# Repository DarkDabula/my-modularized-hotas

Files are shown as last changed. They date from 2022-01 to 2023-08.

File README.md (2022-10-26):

# My Modularized HOTAS
A modularized, mostly 3D printed HOTAS with HID emulation via Arduino

## Motivation
On Christmas 2020 I stumbled over [Elite Dangerous](https://www.elitedangerous.com/) and got hooked. After a while I began to play it in VR.
At this point I realized I would need a HOTAS system. The problem was that through the pademic all systems were mostly sold out. 
I had already a joystick so I built a throttle lever made of metal parts, wood and some electronics. And it served me pretty well.

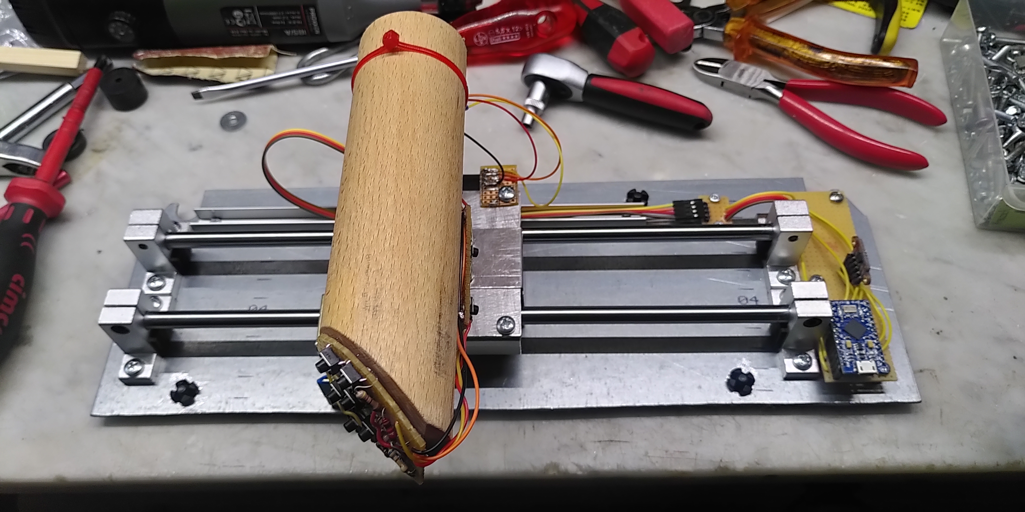
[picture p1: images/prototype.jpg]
Prototype


But after hundreds of hours I recognized that the simple push buttons got weak and that I would need more buttons for effective playing in VR.
In 2021 I bought a 3D printer and the idea was born to contruct a new and better throttle lever and maybe after this a new joystick.

## Goals
- As much 3D printed parts as possible and reasonable
- Modularized design for easy printing, assembly, customization and repair

## Current state
See [here](./status.md)

## Concepts
See [here](./concepts.md)

## External parts
For this project additional parts/components are needed besides the 3D printed ones.

| ID | Ammount | Item | Picture | Example link for buying |
|---|---|---|---|---|
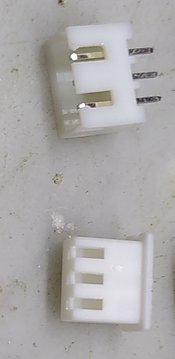
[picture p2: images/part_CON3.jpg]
Connector 3 pins
| CON3 | 3  | Connector 3 pins |  | |
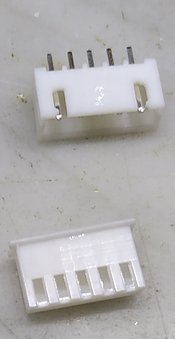
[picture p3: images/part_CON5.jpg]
Connector 5 pins
| CON5 | 1  | Connector 5 pins | | |
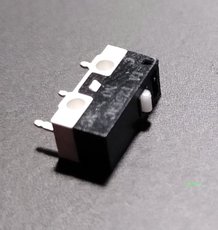
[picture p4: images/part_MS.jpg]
Micro switch
| MS | 4  | Micro swith |  | [Link](https://www.ebay.com/sch/i.html?_from=R40&_trksid=p2380057.m570.l1313&_nkw=micro+limit+switch+125V+1A&_sacat=0) | 
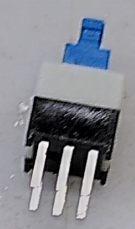
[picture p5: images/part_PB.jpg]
Push button
| PB | 10  | Push button |   | [Link](https://www.ebay.com/sch/i.html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) |
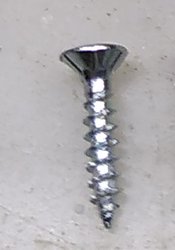
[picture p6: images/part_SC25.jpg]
Screw 2,5x13
| SC25 | 4  | Screw 2,5x13 (metric)  |  | |
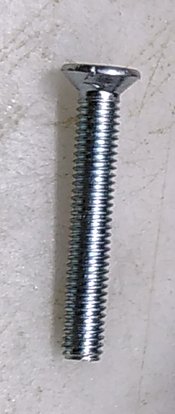
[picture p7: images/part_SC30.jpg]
Screw M3x20
| SCM3 | 1  | Screw M3x20 (metric) |  | |
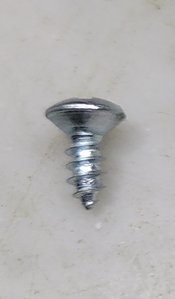
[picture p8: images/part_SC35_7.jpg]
Screw 3,5x7
| SC35_7 | 1  | Screw 3,5x7 (metric) |  | |
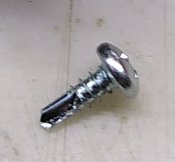
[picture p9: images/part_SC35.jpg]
Screw 3,5x9,6
| SC35_95  | 4  | Screw 3,5x9,5 (metric) |  | |
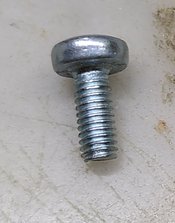
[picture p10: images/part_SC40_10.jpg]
Screw M4x10
| SCM4_10  | 8  | Screw M4x10 (metric) |  | |
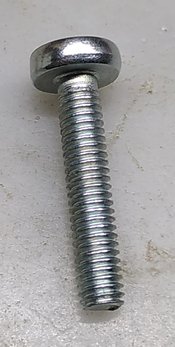
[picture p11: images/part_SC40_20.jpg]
Screw M4x20
| SCM4_20  | 2  | Screw M4x20 (metric) |  | |
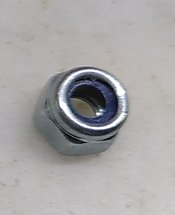
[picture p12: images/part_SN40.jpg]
Stop nut M4
| SCN4 | 2  | Stop nut M4 (metric) |  | |

## Toolchain
- [FreeCAD](https://www.freecad.org/) 0.19
- [Cura](https://ultimaker.com/software/ultimaker-cura) 4.12.1 (or above)
- [Creality Ender 6](https://www.creality.com/goods-detail/ender-6-3d-printer) (modified)
- [Arduino IDE](https://www.arduino.cc/en/software)
- [KiCad](https://www.kicad.org/)

## License
This projects is licensed under the terms of [CC BY-NC 4.0](https://creativecommons.org/licenses/by-nc/4.0/)

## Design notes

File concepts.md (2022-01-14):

# Thoughts and concepts

## HOTAS devices
### Throttle lever
The throttle lever should contain following controls
- 4 buttons and one HAT control for the thumb
- 2 buttons for the forefinger
- a rocker switch for the longfinger and fourth finger

### Joystick
- 2 buttons, one HAT control and one analogue stick
- a rocker switch for the forefinger and longfinger, the rocker switch should be able to press both buttons at the same time
- maybe more

## Modularization
To make the whole design process easier, each control(-group) will be in a separate module. The separate modules will be attached wihin the throttle lever and joystick.

### Control modules
The possible control could be put into following categories
- 2 button control
- rocker switch (two variants: one or two buttons at the same time pushable)
- HAT control
- analogue stick

### Sizes and forms
Maybe its possible to standardize the size and form of the modules so they can be exchanged. It's thinkable that the control types could be grouped in the following manner
- 2 button module, rocker switch module
- HAT module, analogue stick module

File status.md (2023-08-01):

# Status
This file will be a kind of diary for the project, to document the progress

## 1. Aug 2023
After the current lever joint got weaker and weaker I was forced to continue the project and beind able to play Elite Dangerous ^^ I printed the tow new joint parts for the new base plate. While assembling the new parts I recognized the whole cable management within the lever body is a mess. To it will be on my list when I replace the 2nd Arduino with a GPIO expander.

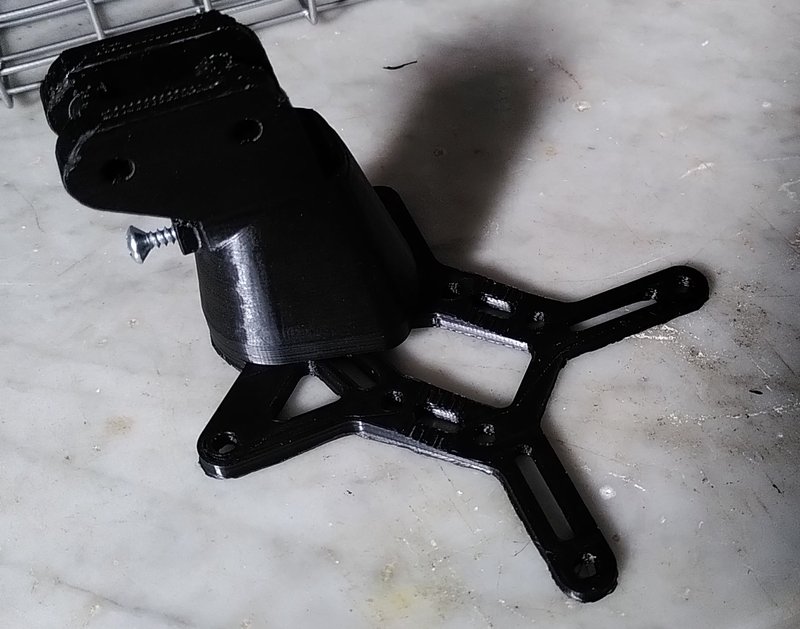
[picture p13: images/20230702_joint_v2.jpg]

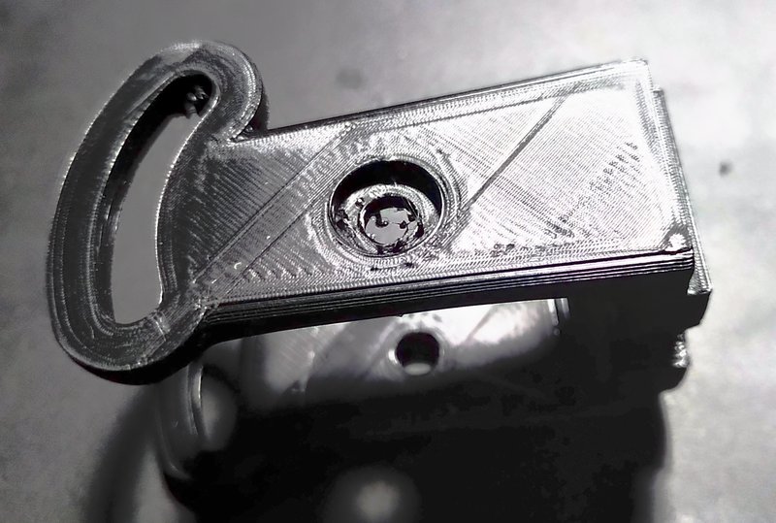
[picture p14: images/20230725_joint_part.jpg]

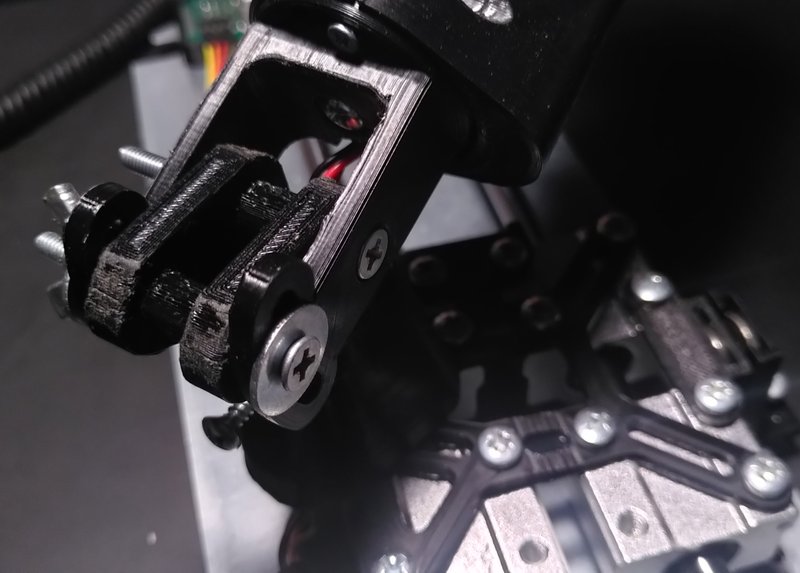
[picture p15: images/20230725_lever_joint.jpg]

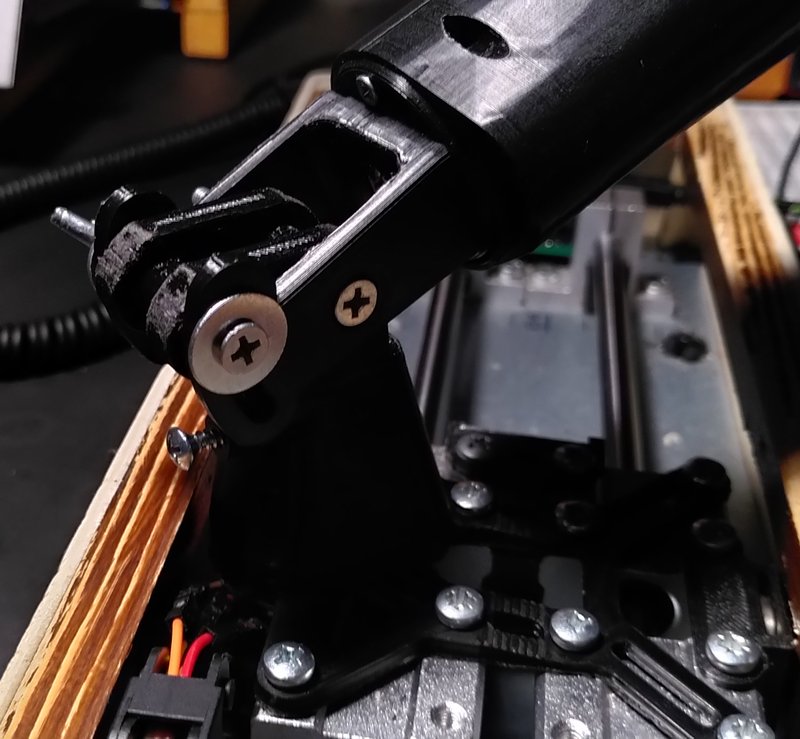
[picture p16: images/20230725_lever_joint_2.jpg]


The screws are still too long, I will replace or shorten them. The advantage is that cou can adjust the vertical angle steplessly. The joint is pretty robust so far even in stressful situations like space comat.

## 28. Jun 2023
Designed and printed a new base plate for the upcoming new lever joint.
I tried to improve stability while reducing the needed material. I also increased the size of the tunnel within the vertical joint for better cable handling.

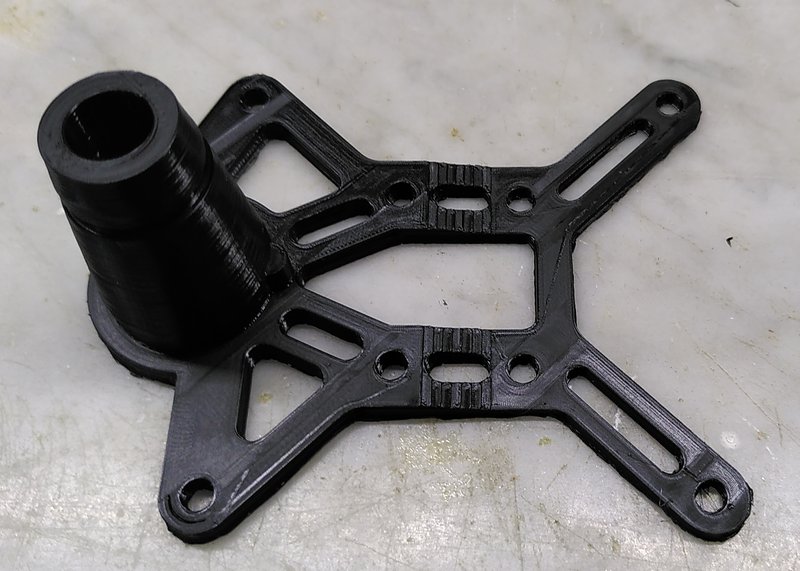
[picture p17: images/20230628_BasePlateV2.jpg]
New base plate


## 23. Apr 2023
I finished another major step, I replaced the lever head with the new version with Cherry MX switches. I am looking forward to play with them. I am not happy with the slight wiring chaos within the lever, I will try to fix it with one of the nest stages.

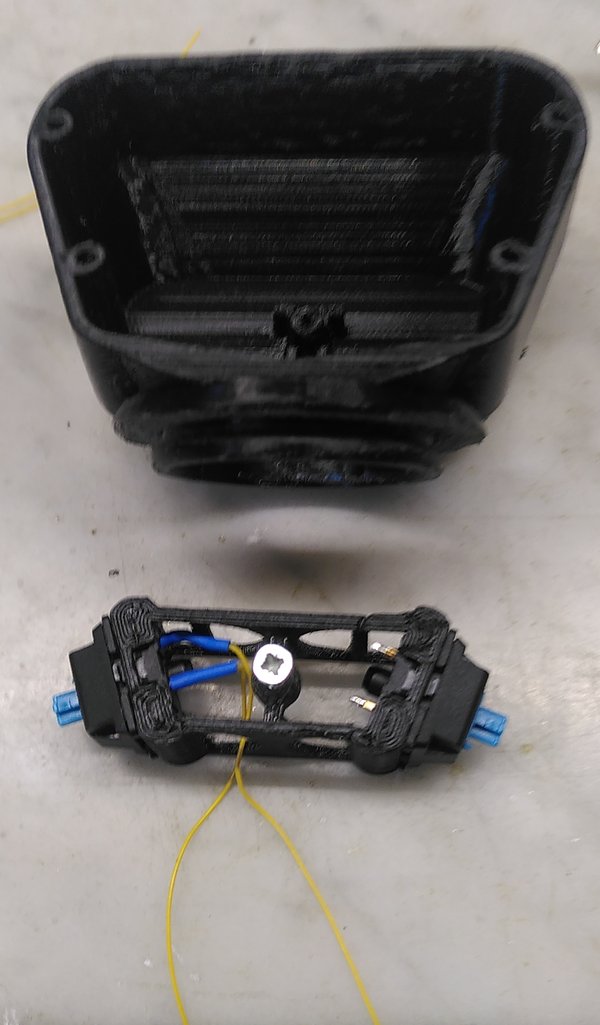
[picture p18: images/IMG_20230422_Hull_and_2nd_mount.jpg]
New hull and secondary mount

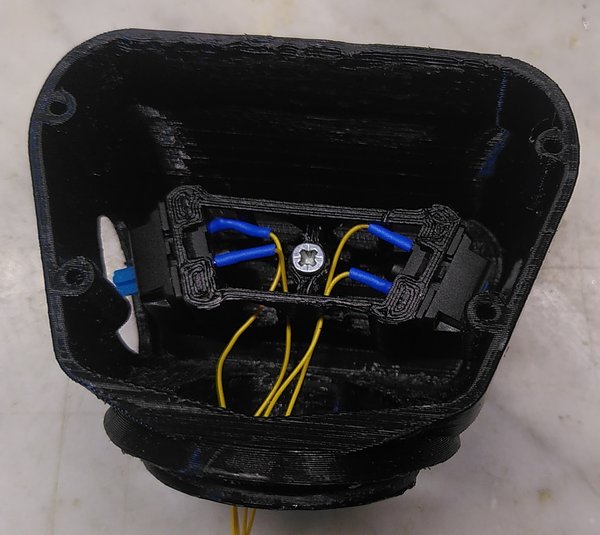
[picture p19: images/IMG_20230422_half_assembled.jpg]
Hull and secondary mount assembled

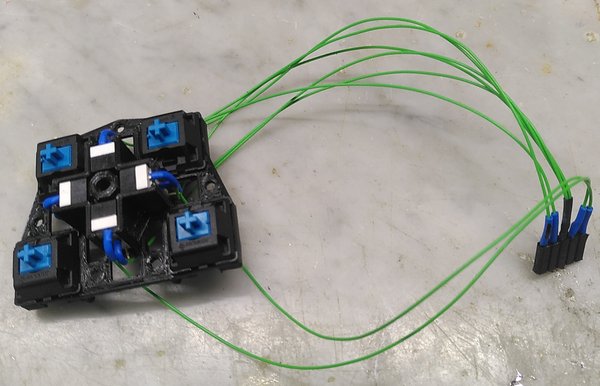
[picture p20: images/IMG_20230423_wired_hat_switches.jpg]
HAT switches wired

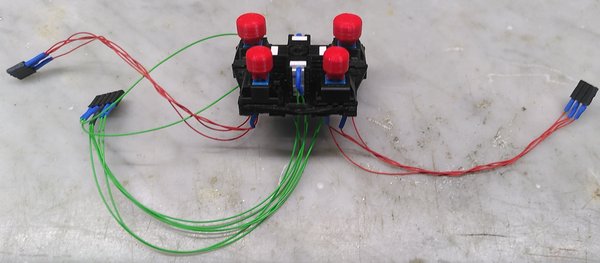
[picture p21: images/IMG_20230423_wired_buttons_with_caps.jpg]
Wired switches and attached caps

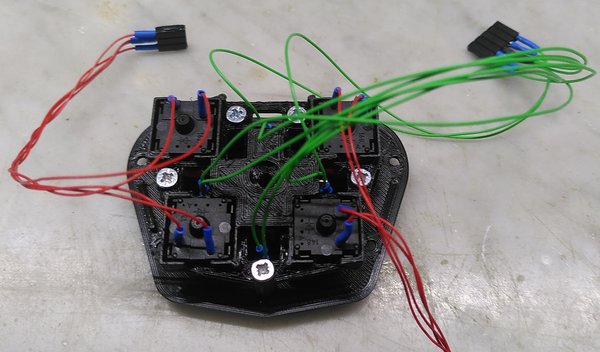
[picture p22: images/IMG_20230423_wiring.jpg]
Wiring from below

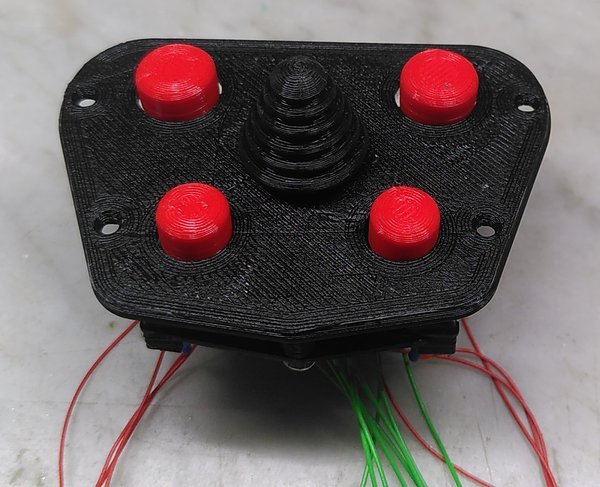
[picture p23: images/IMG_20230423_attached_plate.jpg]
Attached cover plate

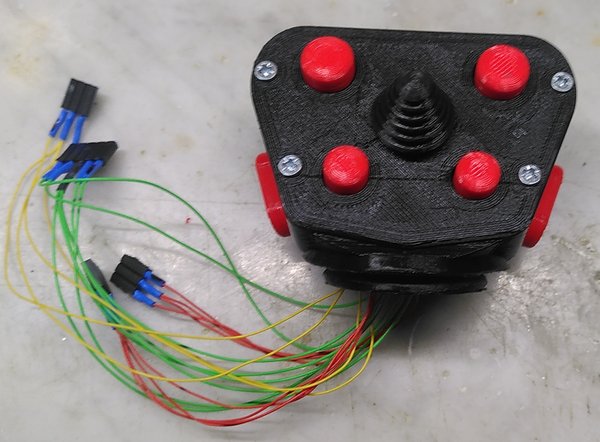
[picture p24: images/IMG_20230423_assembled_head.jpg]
Fully assembled lever head

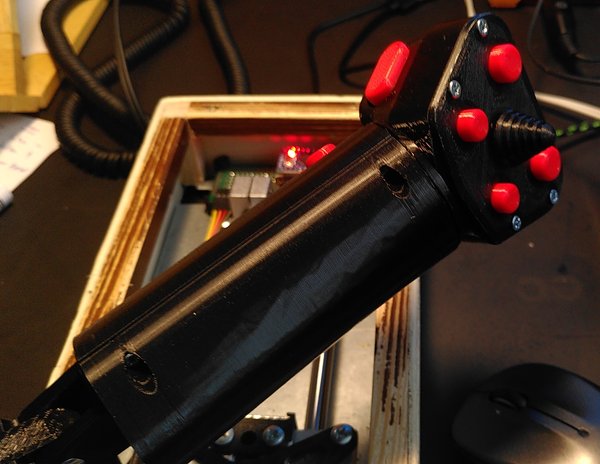
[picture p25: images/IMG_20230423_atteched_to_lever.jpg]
New head attached to lever


The next steps will be
* Replacing the weak mount to the base
* Replacing the inner Arduino and complex resistor board board by an I2C GPIO expander
* Improving wire management

## 06. Mar 2023
Yesterday I completed and assembled the new redesigned lever body. Now there will be Cherry switches for the rocker and the two main buttons. The new body is mostly compatible with the other legacy parts.

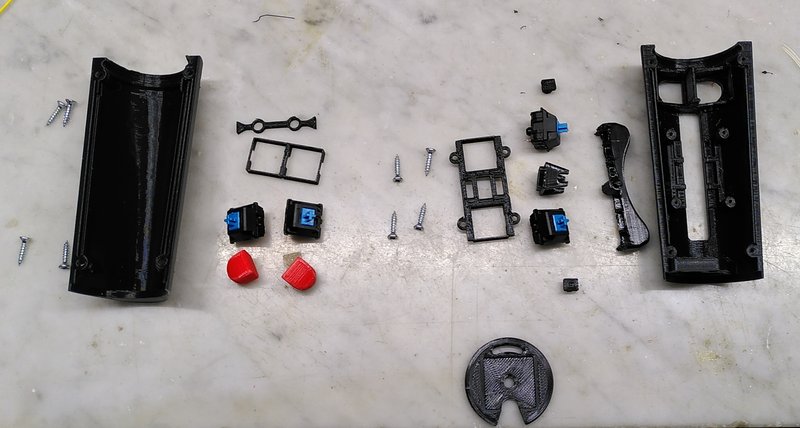
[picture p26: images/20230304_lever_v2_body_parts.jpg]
Parts for lever body V2

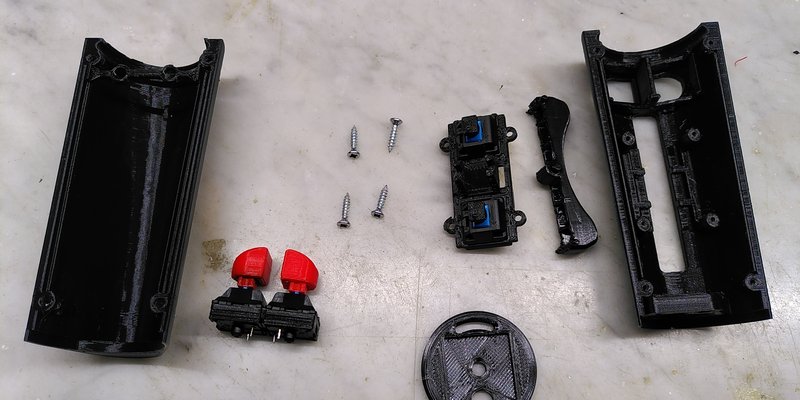
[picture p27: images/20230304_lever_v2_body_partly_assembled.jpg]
Parts for lever body V2 assembled

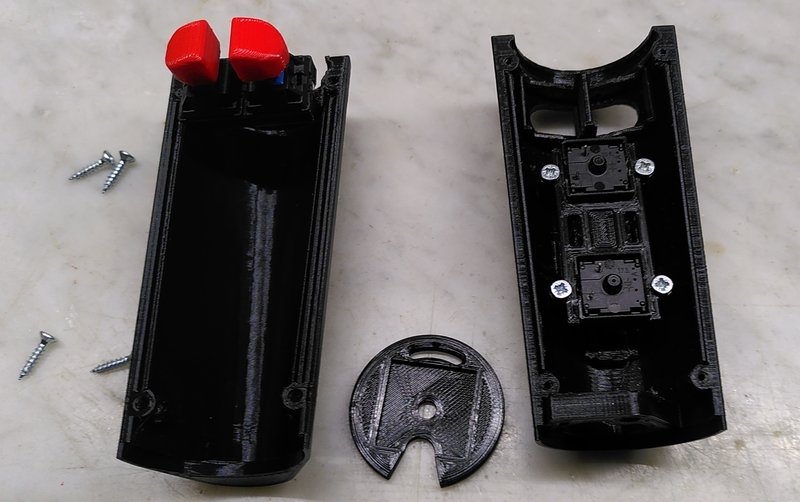
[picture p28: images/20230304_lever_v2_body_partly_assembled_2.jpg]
Parts for lever body V2 assembled

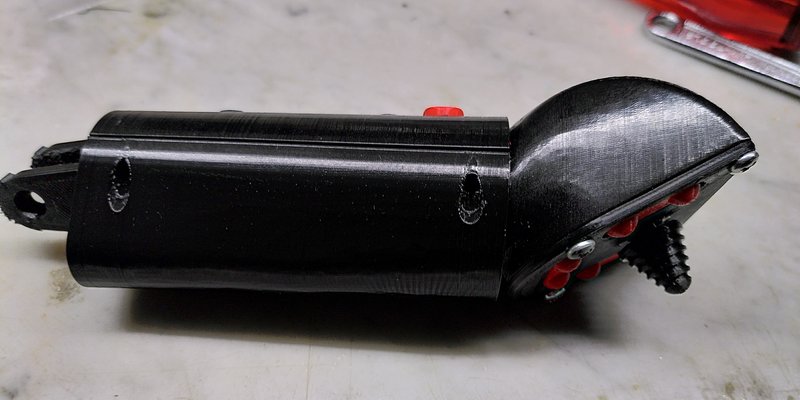
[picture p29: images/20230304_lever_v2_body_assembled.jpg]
Lever body V2 assembled


To connect the cherry keys I use thinner wires and female sockets as connector which fits into the original board connectors.

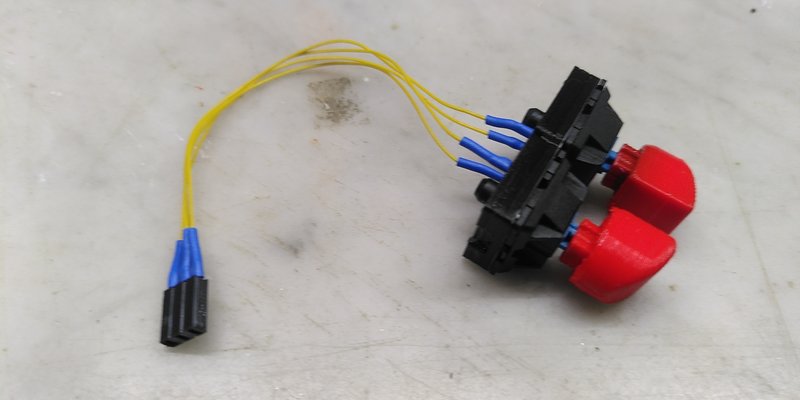
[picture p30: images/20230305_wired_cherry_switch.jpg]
Wired Cherry switches

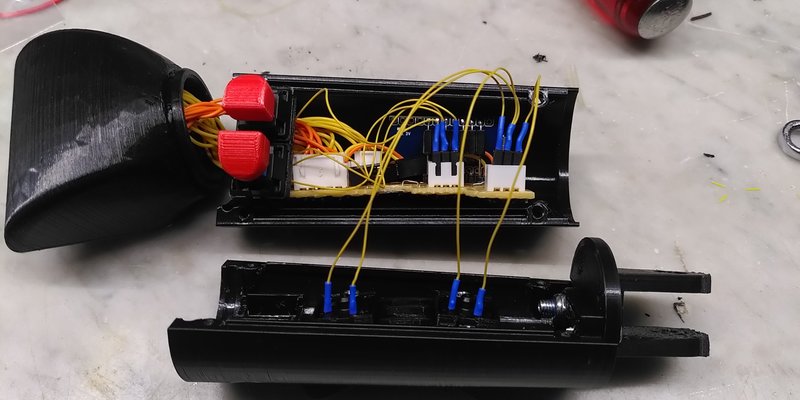
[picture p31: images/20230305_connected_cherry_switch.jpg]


The next steps will be (maybe not in this order):

- Redesign of the lever joint
- Redesign of the HAT-button-panel
- Replacing the inner Arduino and connector board by an I2C GPIO expander

I played already several hours with the new lever and so far all in fine. The Cherry switches are softer and need less pressure. Hopefully the (used) Cherry switches will be more durable.

## 05. Feb 2023
Still playing a lot Elite Dangerous with the current HOTAS design and yes, the blue push buttons are crap. The most stressed button have to be replaced regularly and I am going to run low on replacements.

So I ordered an used Cherry keyboard and desolded the switches. The I designed an printed some prototypes as mount and key cap.

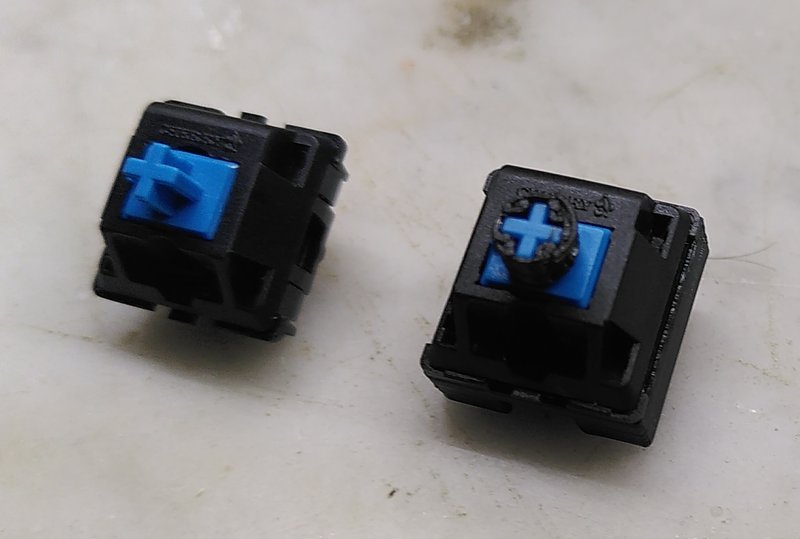
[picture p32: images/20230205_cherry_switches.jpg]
Cherry MX switches with mount prototypes


The next steps will be to redesign the lever and some other parts around the new switches.

## 23. Dec 2022
I printed a cable mount so there will be no mechanical force on the Arduino board anymore.

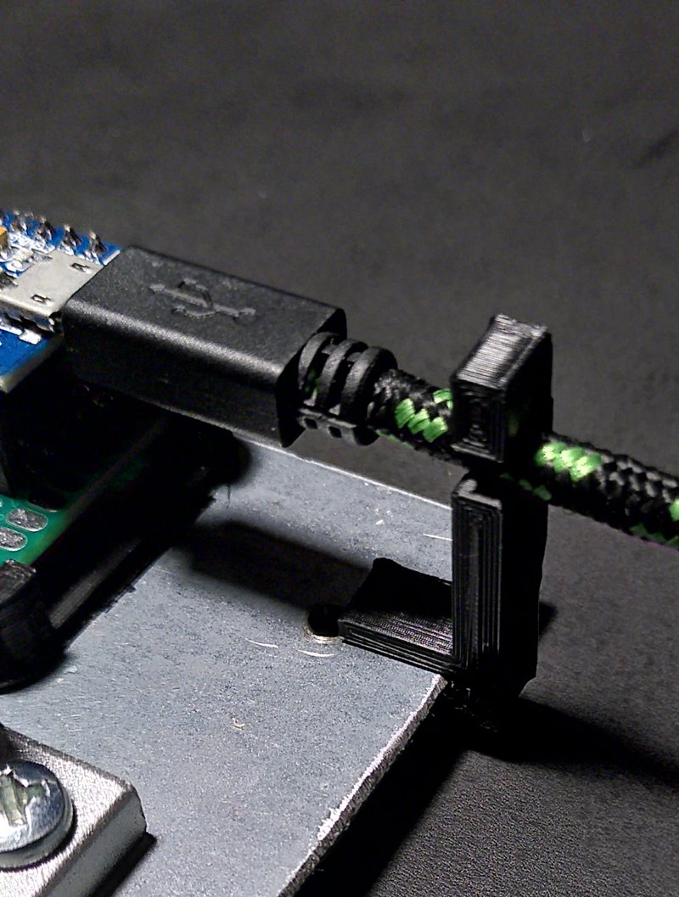
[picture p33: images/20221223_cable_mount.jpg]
Cable mount


I also located some weak points of the construction after several hours playing Elite Dangerous:

- The lever joint seems not strong enough to hold the lever in the adjusted position when pushed to hard
- Some of the push button are getting unreliable. Maybe they don't have the quality I thought. Maybe ne next time I will use real Cherry buttons when possible.
- The circuit with the resistant maybe isn't the best option with the tolerance of the buttons, maybe the next stage will be using a I2C GPIO expander to get an input for every button. 

## 20. Nov 2022
I optimized the code of the master Arduino to improve the throttle control, now it works fine.

I also redesigned the magnet mount for the metal base plate. Unluckily I broke some uncritical parts of it while inserting the magnet.
The new mount have a better adhesion to the plate.

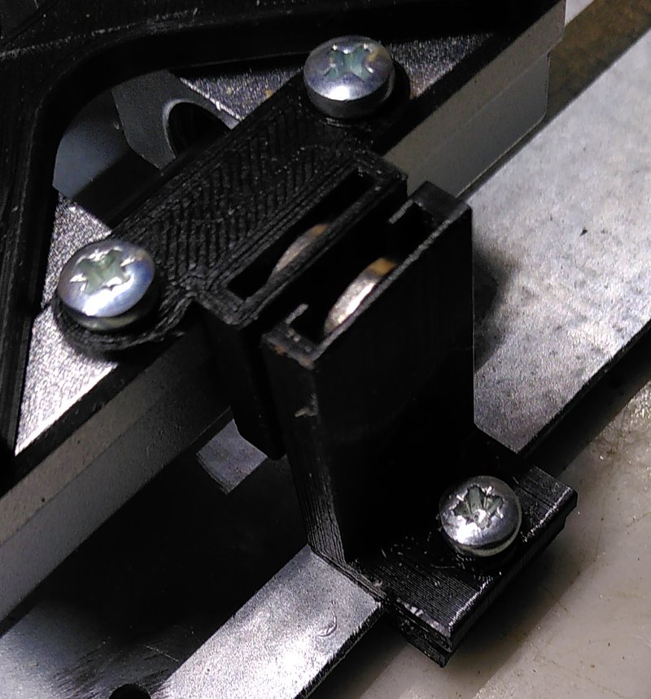
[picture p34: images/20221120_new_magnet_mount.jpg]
New magnet plate mount


I printed a mount for the front board and attached it to the metal base plate.

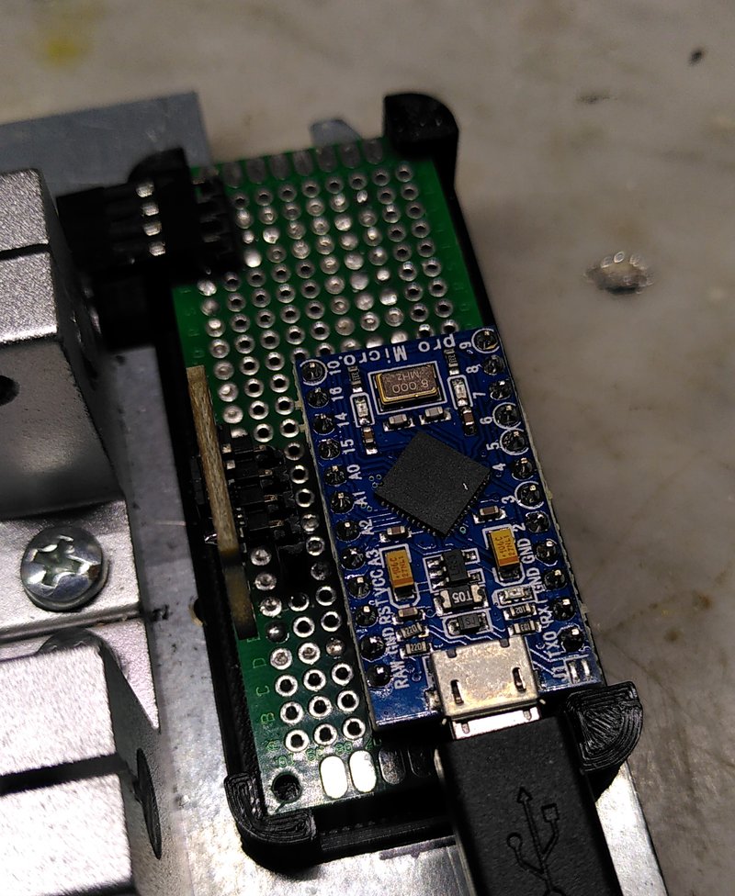
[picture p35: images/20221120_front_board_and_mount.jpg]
Front board and mount


Next step will be to create a case for the whole thing and finalize the cable management.

## 17. Nov 2022
I fixed some issues which occurs while playing.

1. Broken cable at one of the rocker switches
2. Replaced one rocker switch which had more than 30 Ohm while pressed
3. Fixed software bug in slave program which reports invalid values to master via I2C

I also finished the front board with the connectors for cable, time-of-flight sensor and master Arduino

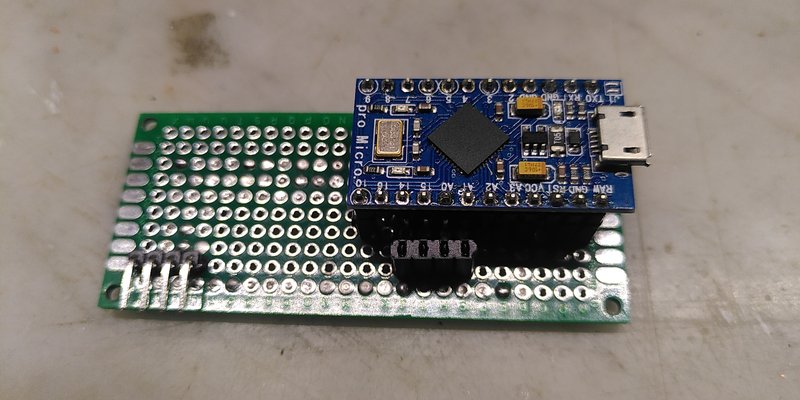
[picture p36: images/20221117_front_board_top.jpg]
Front board top

Front board bottom

Next step is to print a mount for the front board.

## 14. Nov 2022
I wired and assembled the lever

Lever interior
Lever assemlbed

I also printed the last parts for the magnets which "mark" the zero position

Lever interior

and the reflector for the time-of-flight sensor using a small piece of aluminum

Lever interior

I finished the programming of the Arduinos. A strange thing is that sometimes the master gets values over I2C which the slave don't send. 
But luckily I was able to compensate it via programming.

Finally I finished my first session Elite Dangerous with the new lever and configured the key bindings.

## 11. Nov 2022
I finished the connector board

Connector board front
Connector board back

But despite all digital planning I had to modify some parts because the Arduino collided with the 4-pin connector on the side

Connector board modified

1. Removed the plastic spacer to lower the height
2. Cable connection instead pins
3. Increased angle of connector

With that all fits together well

Connector board assembled

I also tested the whole setup with both Arduino boards.

Two Arduinos connected

Next steps will be:

* Finish programming
* Assemble thrust lever
* Create electric connections

## 04. Nov 2022
I designed a placeholder for the boards within the lever to get a feeling for the available space.

Board placeholder

Then I imported the shape into KiCad and puzzled to get all parts arranged within it.

Connector board front
Connector board back

Now I wait for some parts that I ordered to assemble the connector board.
I also continued developing the Arduino sketch for the slave controller.

## 26. Oct 2002
I designed the connector boards with KiCad. These boards will be connected to the buttons and will translate them into analogue signals for the slave Arduino. Maybe this will not be the final design.

Connector boards front
Connector boards back

I also created a physical version, but its not perfect. So I consider to call it prototype.

Connector one board front
Connector one back front

Besides that I began to program the slave Arduino. Results are promising so far.

## 19. Oct 2022
I reached a major milestone within this project. All basic parts of the lever are designed and printed. 

Lever front
Lever back
Lever opened

Not all is perfect but I think it will go through some iterations while using it, but for now I am happy wight the result.

The next phase will be wiring all the buttons, create connector boards and programming the controller. Challenging will be the limited space within the lever.

## 18. Oct 2022
I finally printed the two parts of the lever hull. I printed them separately in two runs. At the first part I struggled to strip the support structure away. So at the second
part I used tree support.

Lever hull parts

There a still some little tasks ahead: 
- reprint of the lever angle stopper -> seems to be too small
- print the final version of the rocker
- print the final version of the rocker module
- designing and printing the front buttons of the lever

## 08. Oct 2022
I redesigned the rocker module to use the new push buttons and omitting the springs.

New rocker module in parts
New rocker module assembled

## 03. Oct 2022
The right panel is now fully assembled and wired. One major step is done.

Right panel assembled

Next phase is the final design for the lever corpus.

## 28. Sep 2022
It took four attempts to print a perfect fitting HAT. I am pretty happy how it worked out finally. The next step will be to create an assembly description with the needed screws and other parts.

Right panel with HAT

## 27. Sep 2022
The right panel makes progress. I printed the cover plate an the double button caps. The next step will be printing the HAT and add the missing wires.

Right panel and button caps

## 26. Sep 2022
At the moment I am eager to play Elite Dangerous again, so I am pretty motivated to push this project forward ;)
Today I printed the (maybe final) panel for the buttons and the HAT module. I also printed a button cap prototype.
A small problem will be wiring the HAT module because there isn't much space.

Right panel and button cap prototype 

## 25. Sep 2022
I am designing the right main button panel of the thrust lever at the moment. I plan to put there 6 buttons and a HAT.
The HAT module gave me a pretty hard time. First I wanted to use the new blue button but I didn't get the mechanics to work.
So I went back to the first micro switches and with that I got a promising prototype.

Right panel parts prototypes

The next step will be to integrate the HAT module into the panel construction.

## 20. Aug 2022
I designed the right part of the lever where many of the buttons and the HAT will be located. The print went pretty well.

Left part of the lever

I am also struggling designing the button modules. The problem is that the switches I wanted to use aren't pretty compact. So I ordered some others at EBAY hoping that they are as reliable as the old ones.

Switches

## 11. Aug 2022
I designed and printed additional parts for test reasons.

New parts

The consists of:
- Two stoppers to set horizontal angle
- Connector and connection plate to connect the lever with the joint with possible rotation around a additional axis
- Partial printed lever hull, which consists of two parts but I put them too close while printing this time
- Stopper to adjust rotation angle of the lever around its inner axis, not completely assembled

The result is promising but I also identified some weak points.

New parts assembled

There is also room for some optimizations like the amount of needed material.

## 07. Aug 2022
I did a second prototype for a part of the joint that will connect lever and base plate. With the screw the joint can be fixed in its position. The print wasn't 100% accurate but luckily it was at a non-critical point.

2nd prototype base joint
2nd prototype base joint on baseplate

## 06. Jun 2022
I redesigned the base plate to reduce need of filament. Additionally I replaced the original lock-in position by a kind of gear to allow finer angles of adjustment around the vertical axis.
I also do a test print ob the counterpart for it.

2nd prototype of base plate  

## 07. Feb 2022
Printed the first version of the base plate with joint. We will see if the joint is strong and stiff enough.

Base plate

## 06. Feb 2022
Replaced the original metal base plate by a thin printed prototype to check if the holes where at the right position. On the base plate there will a joint to connect it with the lever.

Base plate prototype

## 31. Jan 2022
I created the first test pieces for the adjustable joint. With that it should possible to adjust the angle of the lever in relation to the horizontal line. This was my third try after evaluating other designs.

Joint prototype

## 20. Jan 2022
I did a small revision of the rocker switch module. Its slightly smaller and have holes to reduce material. The rocker itself is black because I was too lazy to change the filament for the test print. ^^

Rocker switch revision 1

## 14. Jan 2022
Today I printed the early version of parts for the rocker switch and assembled them with the switches and springs.

First rocker switch

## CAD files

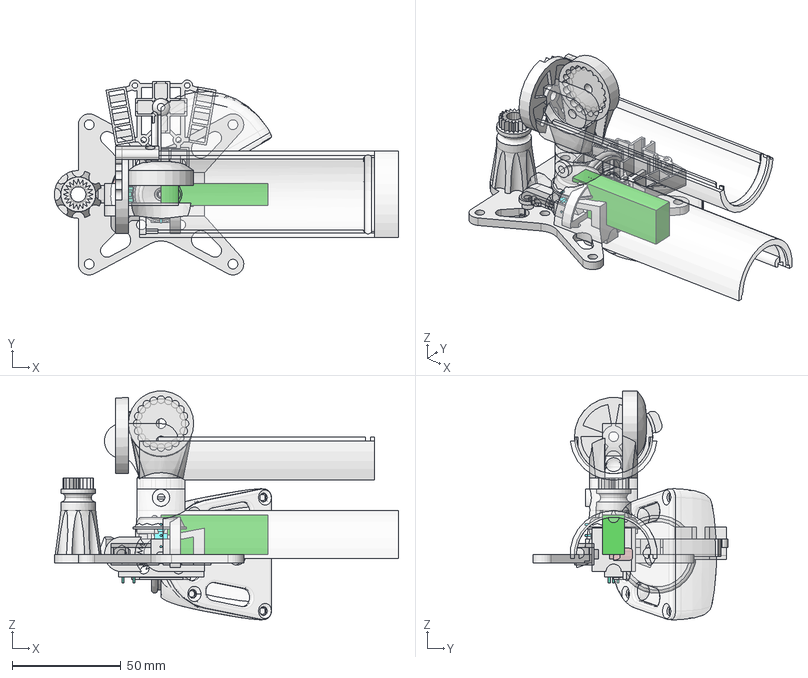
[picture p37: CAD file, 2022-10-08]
freecad/MMHOTAS Throttle Lever.FCStd
157.9 x 89.5 x 105.0 mm
rocker
Micro Switch
Spring
rocker plate bottom
rocker plate top
ProMicro
Plate
Platejoint-Base
Foundation
Vertical adjustable Joint
Vertical joint cap
Joint Connector front
Joint Connector back
Platejoint-Head
Platejoint-Gear
Teeth ring
Adj vertical joint
lc base
Lever front stopper teeth
Lever front stopper base
Lever back stopper teeth
Lever back stopper base
Lever Connector Plate
lc teeth back
lht left end
lht side profile
lhd side profile
Lever Stopper Top
lbpc tube
lbcp ring
lbp plate
tbm switch 2
bc body
bc button north
bc button east
bc button south
bc button west
HAT cap A
HAT cap B
lbpm front buttons
lbpm top buttons
lbpm bottom buttons
HAT cap C
HAT Axe Ring
HAT Switch West
lbpm hat
lbpm front support
lbpm back top support
lbpm back bottom suport
Double Button Cap
HAT Axe Ring 2
rocker body
rm button left
rm button mount
rm rocker mount 2

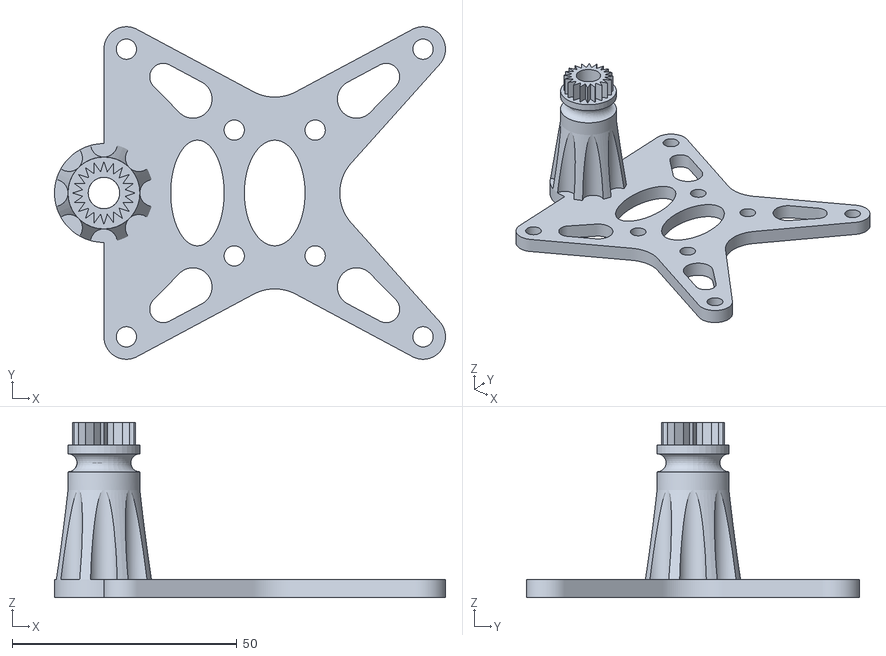
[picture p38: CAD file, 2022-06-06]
stl/MMHOTAS Throttle Lever-Baseplate.stl
87.0 x 74.0 x 39.0

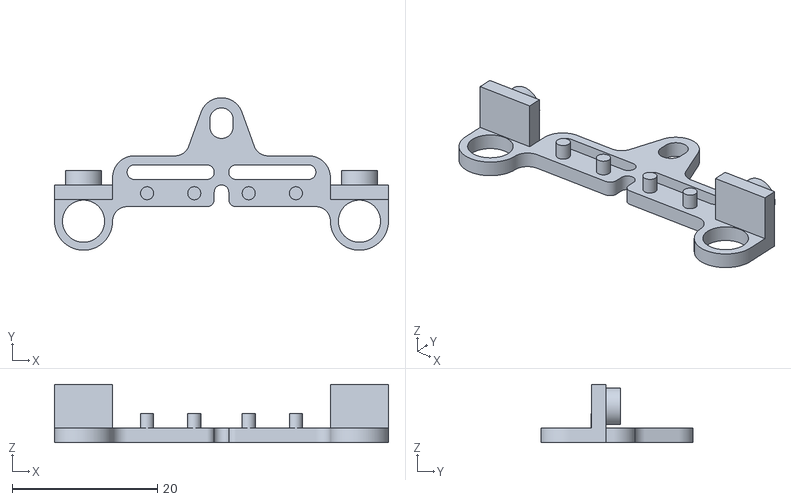
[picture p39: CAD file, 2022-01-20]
stl/MMHOTAS Throttle Lever-rocker module-rocker plate bottom.stl
46.0 x 21.0 x 8.00

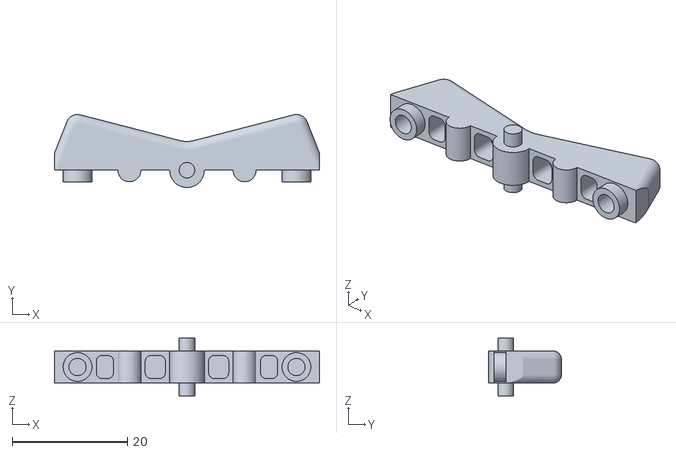
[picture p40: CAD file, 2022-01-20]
stl/MMHOTAS Throttle Lever-rocker module-rocker.stl
46.0 x 12.7 x 10.0

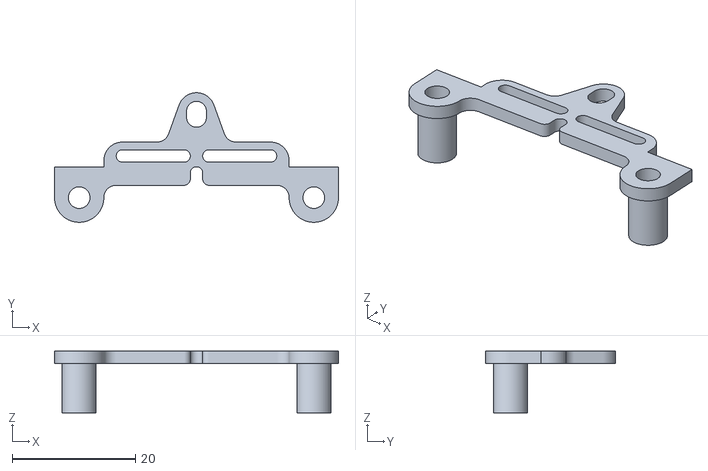
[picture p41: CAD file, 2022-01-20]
stl/MMHOTAS Throttle Lever-rocker module-rocker plate top.stl
46.0 x 21.0 x 10.0

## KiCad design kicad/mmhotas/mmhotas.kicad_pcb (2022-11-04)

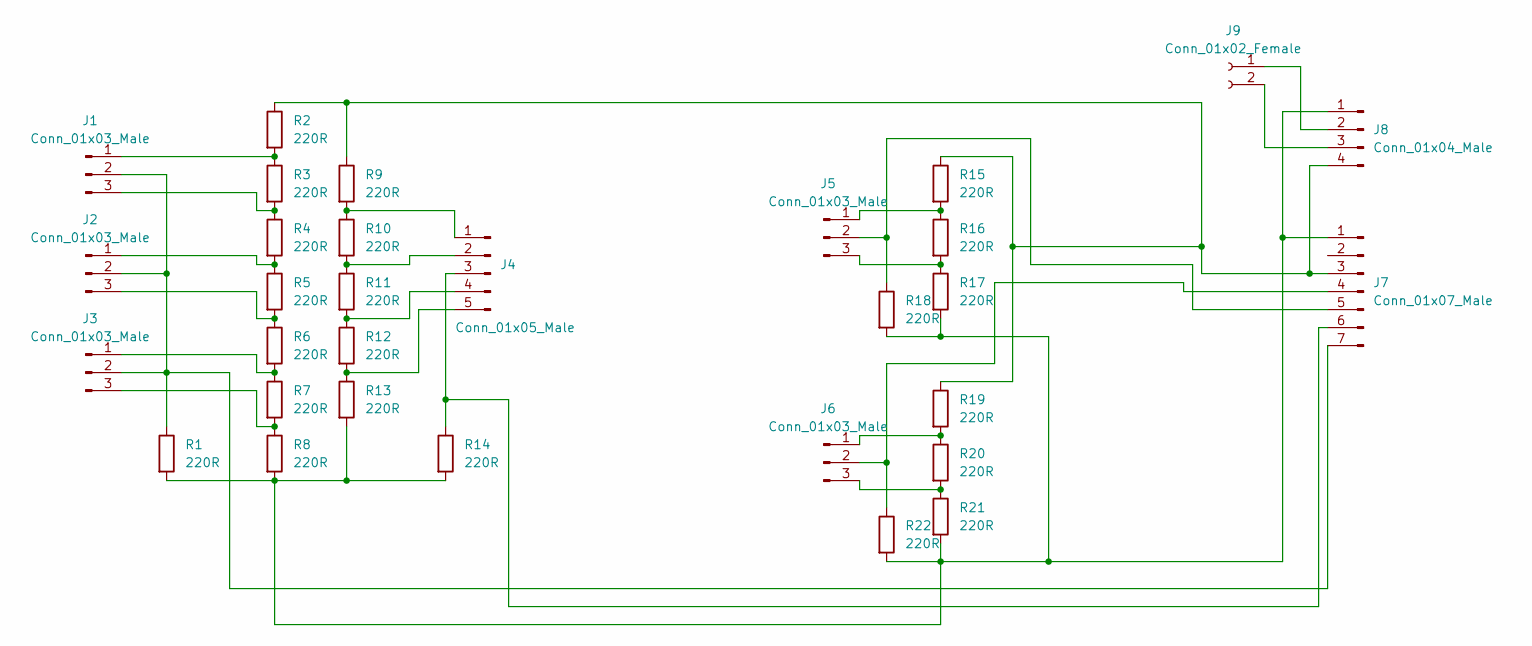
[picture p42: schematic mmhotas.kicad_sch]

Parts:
J1, J2, J3, J5, J6: Conn_01x03_Male; JST_XH_B3B-XH-A_1x03_P2.50mm_Vertical
J4: Conn_01x05_Male; JST_XH_B5B-XH-A_1x05_P2.50mm_Vertical
J7: Conn_01x07_Male; PinHeader_1x07_P2.54mm_Vertical
J8: Conn_01x04_Male; PinHeader_1x04_P2.54mm_Horizontal
J9: Conn_01x02_Female; PinSocket_1x02_P2.54mm_Vertical
R1, R2, R3, R4, R5, R6, R7, R8, R9, R10, R11, R12, R13, R14, R15, R16, R17, R18, R19, R20, R21, R22: 220R; R_1206_3216Metric

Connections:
unnamed: J1.1, R2.2, R3.1
unnamed: J1.2, J2.2, J3.2, J7.7, R1.1
unnamed: J1.3, R3.2, R4.1
unnamed: J2.1, R4.2, R5.1
unnamed: J2.3, R5.2, R6.1
unnamed: J3.1, R6.2, R7.1
unnamed: J3.3, R7.2, R8.1
unnamed: J4.1, R9.2, R10.1
unnamed: J4.2, R10.2, R11.1
unnamed: J4.3, J7.6, R14.1
unnamed: J4.4, R11.2, R12.1
unnamed: J4.5, R12.2, R13.1
unnamed: J5.1, R15.2, R16.1
unnamed: J5.2, J7.5, R18.1
unnamed: J5.3, R16.2, R17.1
unnamed: J6.1, R19.2, R20.1
unnamed: J6.2, J7.4, R22.1
unnamed: J6.3, R20.2, R21.1
unnamed: J7.1, J8.1, R1.2, R8.2, R13.2, R14.2, R17.2, R18.2, R21.2, R22.2
unnamed: J7.3, J8.4, R2.1, R9.1, R15.1, R19.1
unnamed: J8.2, J9.1
unnamed: J8.3, J9.2

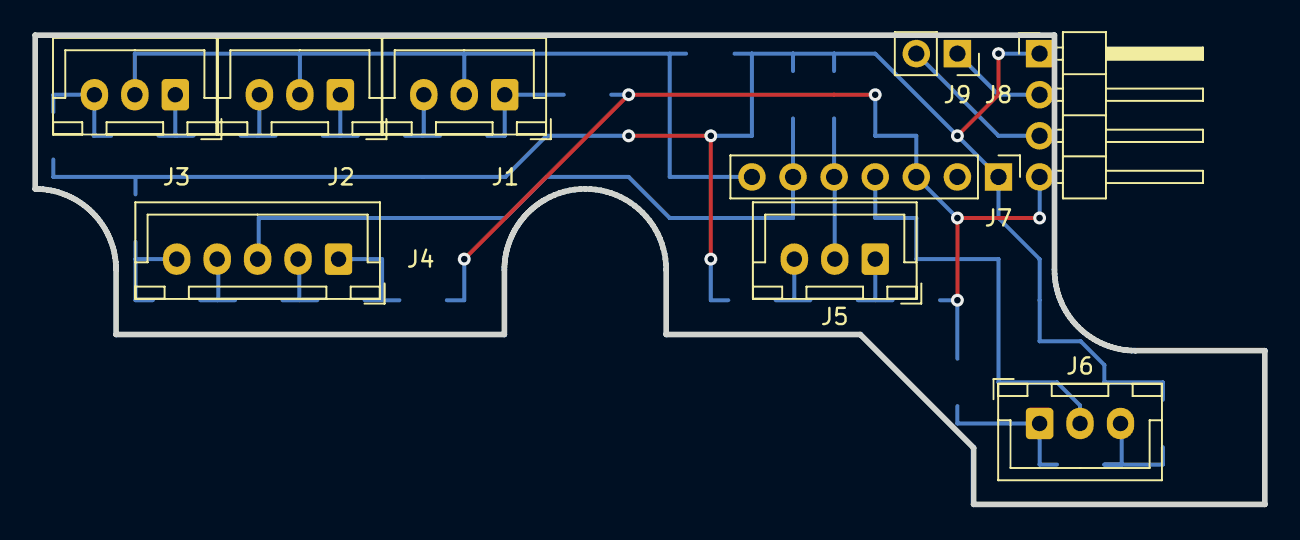
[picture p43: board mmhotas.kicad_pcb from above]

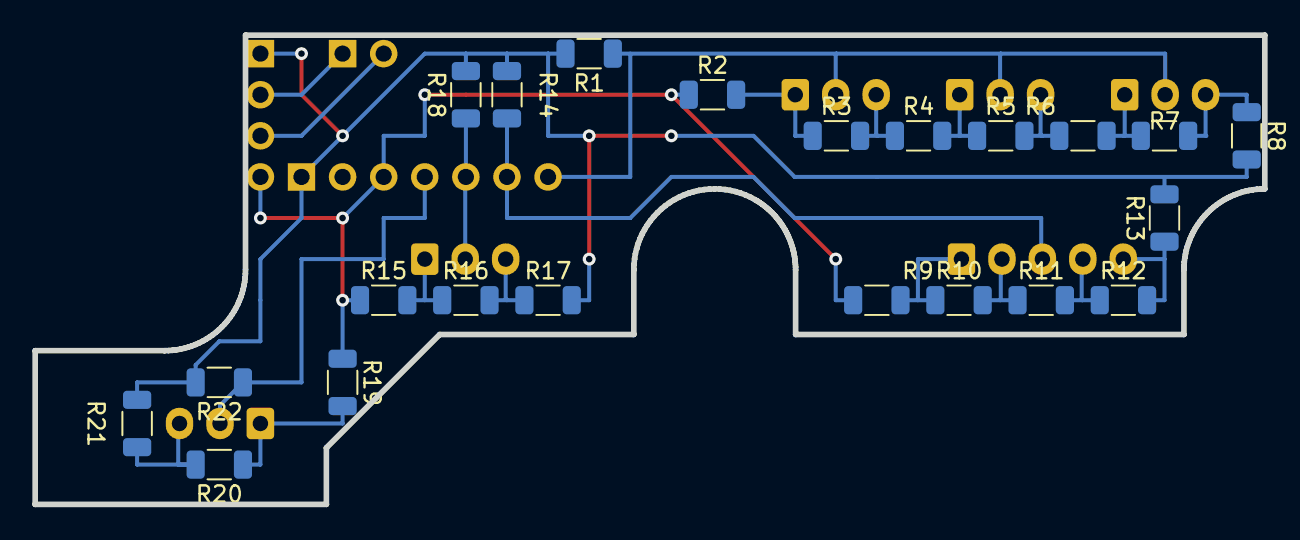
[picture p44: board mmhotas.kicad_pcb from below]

Board: 2 copper layers, 76.0 x 29.0 mm, 31 parts (22 on the bottom side), 22 nets.

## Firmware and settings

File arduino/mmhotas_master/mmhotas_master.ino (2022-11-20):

 /**
 * Sketch for the master board of the My Modularized HOTAS project
 * 
 * https://github.com/DarkDabula/my-modularized-hotas
 * 
 * Licensed with CC BY-NC 4.0
 * https://creativecommons.org/licenses/by-nc/4.0/
 */

/**
 * Includes
 */

// Needed for I2C
#include "Wire.h"

// Joystick HID - Source: https://github.com/MHeironimus/ArduinoJoystickLibrary/tree/version-2.0
#include <Joystick.h>

// TOF Sensor
// Library from Pololu - Source https://github.com/pololu/vl53l0x-arduino
#include "VL53L0X.h"

/**
 * Here is general global stuff like definitions
 */

// Global debug flag, uncomment to enable serial port and outputs
//#define DEBUG 1

// Joystick object - 8 Buttons, one HAT, rudder and throttle
Joystick_ Joystick = Joystick_(0x04, JOYSTICK_TYPE_JOYSTICK, 8, 1, false, false, false, false, false, false, true, true, false, false, false);

// TOF Sensor for throttle
VL53L0X lox = VL53L0X();

// Main throttle table to translate distance values into throttle values
// Format is minDist, throttleVal
// throttleVal is defined as
//    -100, 100 - min/max
//    -1, 1     - linear range
//    0         - center 
//
int throttleTable[6][2] = 
{
  {-999, 100},  // 100%
  {5, 1},       // linear +
  {105, 0},     // 0%
  {115, -1},    // linear -
  {190, -100}   // -100%
};

// Zone around the center position considered as center in millimeters
int throttleCenterZone = 7;

/**
 * Helper functions
 */
 void initJoystick()
 {
   // Setup joystick
   Joystick.setThrottleRange(-100, 100);
   Joystick.setRudderRange(-100, 100);
   
   Joystick.begin(false);
   Joystick.setThrottle(0);
   Joystick.setRudder(0);
 }

 void initLOX()
 {
    // Measuring timeout is 100ms
    while(!lox.init()) delay(10);
    lox.setMeasurementTimingBudget(50000);
    delay(2000);

    // Take some measurements to retrive actual center value
    int throttleCenter = lox.readRangeSingleMillimeters();
    for(int i = 0; i < 10; i++)
    {
      throttleCenter += lox.readRangeSingleMillimeters();
      throttleCenter /= 2;
    }

    // With the actual center value we change the center range in the throttle table
    throttleTable[2][0] = throttleCenter - throttleCenterZone;
    throttleTable[3][0] = throttleCenter + throttleCenterZone;
 }

 // Translate external states into Joystick state
 //
 // @param tofPos Positions on TOF sensor in millimeters
 // @param buttonStates Button states reported by the slave adruino. The value have the following format
 //         Bits 0 to 3: SixButtons group (value 0 to 6)
 //         Bits 4 to 7: HAT (value 0 to 8)
 //         Bits 8 to 11: TwoButtons group (value 0 to 2)
 //         Bits 12 to 15: Rocker (value 0 to 2)
 //
 void sendJoystickState(int tofPos, int buttonStates)
 {
    signed short val = 0;
  
    // Translate throttle
    //
    signed short throttleValue = 0;
    unsigned short throttleEntry = 0; 
   
    #ifdef DEBUG
      Serial.println("Calculating throttle:");
    #endif
  
    for(short i = 0; i < 5; i++)
    {
      // Find the last matching entry
      if(tofPos >= throttleTable[i][0])
      {
        throttleValue = throttleTable[i][1];
        throttleEntry = i; 
      }
      else break;
    }

    #ifdef DEBUG
      Serial.print("- Found throttle table entry ");
      Serial.print(throttleEntry);
      Serial.print(" with value ");
      Serial.println(throttleValue);        
    #endif
 
    // When within a linear interval, do some calculations
    if(abs(throttleValue) == 1)
    {
      // This part is a bit tricky because we have to use the next table entry to calculate the linear value wthin the range
      int intervalRange = abs(throttleTable[throttleEntry][0] - throttleTable[throttleEntry + 1][0]);  
      #ifdef DEBUG
        Serial.print("- Linear range is: ");
        Serial.println(intervalRange);
      #endif

      // Here we calculate the distance from reference point debending on the direction
      int distanceToReference = (throttleValue > 0) ? (throttleTable[throttleEntry + 1][0] - tofPos) : (tofPos - throttleTable[throttleEntry][0]);
      #ifdef DEBUG
        Serial.print("- Distance to reference is: ");
        Serial.println(distanceToReference);
      #endif

      // With the range and distance we can do simple calculation of percent but we have to regard the sign
      throttleValue = throttleValue * 100.0 * (distanceToReference) / intervalRange;
    }

    #ifdef DEBUG
      Serial.print("Throttle: ");
      Serial.println(throttleValue);
    #endif
    Joystick.setThrottle(throttleValue);

    // Translate buttons
    //
    #ifdef DEBUG
      Serial.print("Buttons: ");
    #endif

    // Buttons 0 and 1
    val = (buttonStates >> 8) & 0xF;
    switch(val)
    {
      case 1:
        Joystick.pressButton(0);
        Serial.print("1 ");
        break;
        
      case 2:
        Joystick.pressButton(1);
        Serial.print("2 ");
        break;
        
      case 3: 
        Joystick.pressButton(0);
        Joystick.pressButton(1);
        Serial.print("1+2 ");
        break;
        
      default:
        Joystick.releaseButton(0);
        Joystick.releaseButton(1);
        break;  
      
    }
    
    // Buttons 2 to 8
    val = buttonStates & 0xF;
    for(int i = 1; i <= 6; i++)
    {
      if(val == i)
      {
        Joystick.pressButton(i+1);
        #ifdef DEBUG
          Serial.print(i+2);
          Serial.print(" ");
        #endif
      }
      else Joystick.releaseButton(i+1);
    }
    #ifdef DEBUG
      Serial.println("");
    #endif

    // Translate HAT
    //
    signed short angleHAT = JOYSTICK_HATSWITCH_RELEASE; // Released at begin
    val = (buttonStates >> 4) & 0xF;
    if(val > 0) angleHAT = (val - 1) * 45;
    #ifdef DEBUG
      Serial.print("HAT: ");
      Serial.println(angleHAT);
    #endif
    Joystick.setHatSwitch(0, angleHAT);

    // Translate rudder
    //
    signed rudderValue = 0;
    val = (buttonStates >> 12) & 0xF;
    // 2 is left -> -100, 1 is right -> 100
    //if(val > 0) rudderValue = val * -100 / val; 
    switch(val)
    {
      case 1:
        rudderValue = 100;
        break;

      case 2:
        rudderValue = -100;
        break;
    }
    #ifdef DEBUG
      Serial.print("Rudder: ");
      Serial.println(rudderValue);
    #endif
    Joystick.setRudder(rudderValue);
    
    // Send state to computer
    //
    Joystick.sendState();
 }


/**
 * Setup routine
 */
void setup() 
{
  // Setup serial port for debugging
  #ifdef DEBUG
    Serial.begin(9600);
  #endif
  
  // Set up I2C bus, needed for slave Arduino and TOF Sensor
  Wire.begin(); // We are the master

  // Setup joystick device
  initJoystick();

  // Setup TOF sensor
  initLOX();
}

/**
 * Main loop
 */
void loop() 
{
  // LED ON
  RXLED1;
  
  // Read and handle TOF
  static int tofLastPos = 0;
  int tofPos = lox.readRangeSingleMillimeters();
  #ifdef DEBUG
    Serial.print("TOF reports: ");
    Serial.println(tofPos);
  #endif

  // Smothing the value a little bit
  tofPos = (tofPos + tofLastPos) / 2;
  tofLastPos = tofPos;

  // LED off
  RXLED0;
  TXLED1;

  // Read slave arduino, its pervert because I2C only reads bytewise
  byte bytesBuffer[sizeof(int)];
  Wire.requestFrom(0x11, sizeof(int));
  while(Wire.available() != sizeof(int)) 
  {
  #ifdef DEBUG
    Serial.println("Waiting for slave ...");
  #endif
    delay(10);
  }  
  for(int i = 0; i < sizeof(int); i++)
  {
    bytesBuffer[i] = Wire.read();
    #ifdef DEBUG
      Serial.print("Receiving byte: ");
      Serial.println(bytesBuffer[i]);
    #endif
  }
  int buttonStates = *((int*)bytesBuffer);
  if(true) // Not needed anymore
  //if(buttonStates >= 0 && buttonStates < 10000) // Sometimes there are invalid values for what reason
  {
    #ifdef DEBUG
      Serial.print("Slave reports: ");
      Serial.println(buttonStates);
    #endif
  }
  else
  {
    #ifdef DEBUG
      Serial.print("Ignoring slave: ");
      Serial.println(buttonStates);
    #endif  
    buttonStates = 0;
  }

  // Translate and send joystick state
  sendJoystickState(tofPos, buttonStates);

  // LED off
  TXLED0;

  // Sleep for a while, only in debug because TOF sensor limits the cycle
  #ifdef DEBUG
    delay(500);
  //#else
  //  delay(50);
  #endif
}

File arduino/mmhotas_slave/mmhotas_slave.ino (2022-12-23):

/**
 * Sketch for the slave board of the My Modularized HOTAS project
 * 
 * https://github.com/DarkDabula/my-modularized-hotas
 * 
 * Licensed with CC BY-NC 4.0
 * https://creativecommons.org/licenses/by-nc/4.0/
 */

#include "Wire.h"


/**
 * Here is general global stuff like definitions
 */

// Global debug flag, uncomment to enable serial port and outputs
//#define DEBUG 1

// Pins
#define pinSixButtons A0
#define pinHAT A1
#define pinTwoButtons A2
#define pinRocker A3

// Value tables to translate analog values into buttons
int valuesSixButtons[] = {75, 120, 160, 215, 300, 465};
int valuesHAT[] = {110, 145, 185, 255, 280, 435, 455, 340}; // N, NW, W, SW, S, SE, E, NE
int valuesTwoButtons[] = {200, 405, 335}; // 1, 2, 1+2
int valuesRocker[] = {405, 195}; // right, left

// Defines a range around the input value for comparison with the value tables
//#define valueValidDelta 9

volatile int buttonStates = 0;

/**
 * Helper functions
 */

// Function to translate analogue values into button states
int evaluateInput(short pinInput, int valuesArray[], size_t arraySize, const char* title, short valueValidDelta = 9)
{
  int valueIO = analogRead(pinInput); 
  int outputValue = 0;
  #ifdef DEBUG
    Serial.print(title);
    Serial.print(": ");
    Serial.println(valueIO);
  #endif
  if(valueIO) 
  { 
    for(size_t i = 0; i < arraySize; i++)
    {
      if(abs(valueIO - valuesArray[i]) <= valueValidDelta)
      {
        outputValue = i+1;
        break;
      }
    }
  }
  #ifdef DEBUG
    Serial.print(" -> Translated: ");
    Serial.println(outputValue);
  #endif
  return outputValue; 
}

// Translates the different button values into one fot I2C transmission
// Each button group will be coded into 4 bits even it would need fewer bits
// Scheme will be:
// Bits 0 to 3: SixButtons group
// Bits 4 to 7: HAT
// Bits 8 to 11: TwoButtons group
// Bits 12 to 15: Rocker
int translateButtonValues(int valSixButtons, int valHAT, int valTwoButtons, int valRocker)
{
  static int lastResult = 0; 
  
  // Translate values into byte package
  int result = 0;
  result |= (valSixButtons & 0xF);
  result |= (valHAT & 0xF) << 4;
  result |= (valTwoButtons & 0xF) << 8;
  result |= (valRocker & 0xF) << 12;

  // We combine value of last translateion with the actual one to supress wrong states
  int returnVal = (result & lastResult);
  lastResult = result;

  return returnVal;
}

// EVent handler when the master requests the actual button states
void sendButtonStates()
{
  #ifdef DEBUG
    Serial.print("Sending button states to master: ");
    Serial.println(buttonStates);
  #endif  

  // LED on
  TXLED1;
  
  // Maybe dirty but we handle the int as an array of bytes
  Wire.write((const byte*)&buttonStates, sizeof(int));

  // LED off
  TXLED0;
}

/**
 * Setup routine
 */
void setup() 
{
  // Setup serial port for debugging
  #ifdef DEBUG
    Serial.begin(9600);
  #endif

  // Set up the input pins
  /*pinMode(pinSixButtons, INPUT);
  pinMode(pinHAT, INPUT);
  pinMode(pinTwoButtons, INPUT);
  pinMode(pinRocker, INPUT);*/

  // Set up I2C bus
  Wire.begin(0x11); // We are the slave
  Wire.onRequest(sendButtonStates);

}

/**
 * Main loop
 */
void loop() 
{
  int valueSixButtons = 0;
  int valueHAT = 0;
  int valueTwoButtons = 0;
  int valueRocker = 0;

  // LED on
  RXLED1;
  
  // Read SixButtons
  valueSixButtons = evaluateInput(pinSixButtons, valuesSixButtons, sizeof(valuesSixButtons) / sizeof(int), "SixButtons");

  // Read HAT
  valueHAT = evaluateInput(pinHAT, valuesHAT, sizeof(valuesHAT) / sizeof(int), "HAT");

  // Read TwoButtons
  valueTwoButtons = evaluateInput(pinTwoButtons, valuesTwoButtons, sizeof(valuesTwoButtons) / sizeof(int), "TwoButtons", 30);

  // Read rocker
  valueRocker = evaluateInput(pinRocker, valuesRocker, sizeof(valuesRocker) / sizeof(int), "Rocker", 30);

  // Translate states
  buttonStates = translateButtonValues(valueSixButtons, valueHAT, valueTwoButtons, valueRocker);

  // LED off
  RXLED0;

  // Sleep for a while
  #ifdef DEBUG
    delay(500);
  #else
    delay(50);
  #endif
}

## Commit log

2022-01-14 Added folder for images and added image of prototype
2022-01-14 Update README.md
    Added link to Arduino IDE
2022-01-14 Added image of first rocker switch
2022-01-14 Added actual STL files for rocker module parts
    [MMHOTAS Throttle Lever-rocker module-rocker plate bottom.stl, MMHOTAS Throttle Lever-rocker module-rocker plate top.stl, MMHOTAS Throttle Lever-rocker module-r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]
2022-01-20 Revision 1 of rocker module
    [MMHOTAS Throttle Lever-rocker module-rocker plate bottom.stl, MMHOTAS Throttle Lever-rocker module-rocker plate top.stl, MMHOTAS Throttle Lever-rocker module-r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]
2022-02-06 Entry for the new base plate
2022-02-08 First version of baseplate
    [MMHOTAS Throttle Lever-Baseplate.stl]
2022-06-06 - New baseplate prototype
    [MMHOTAS Throttle Lever-Baseplate.stl]
2022-08-07 Documented basejoint prototype
2022-08-11 - New parts printed - Some images resized
2022-08-20 - Added images - Added links for external parts - Added FreeCAD file
    [MMHOTAS Throttle Lever.FCStd]
2022-08-20 - Added image for switch
2022-09-25 Protottype for HAT module
    [MMHOTAS Throttle Lever.FCStd]
2022-09-26 Added micro switch to parts list
2022-09-26 Button panel and button cap prototype
    [MMHOTAS Throttle Lever.FCStd]
2022-09-29 Created HAT für richt panel
    [MMHOTAS Throttle Lever.FCStd]
2022-10-08 New rocker module
    [MMHOTAS Throttle Lever.FCStd]
2022-10-18 Printed lever hull
2022-10-26 Designed connector boards
    [mmhotas.kicad_pcb, mmhotas.kicad_sch]
2022-11-04 Designed connector board Backups removed
    [mmhotas.kicad_pcb, mmhotas.kicad_sch]
2022-11-04 Designed placeholder for connector board and Arduino
2022-11-04 Sketch for slave Arduino
2022-11-17 Added debug output for I2C
2022-11-17 Fixed wrond values if analogue value doesn't match table entry
    [mmhotas_slave.ino]
2022-11-17 New images of front board
2022-11-18 Redesigned plate magnet mount
2022-11-20 Rework of throttle translation, more debug message
    [mmhotas_master.ino]
2022-12-23 Modifications to compensate defected buttons
2022-12-23 Added cable and mount preparing new lever joint
2023-02-05 Actual state and new Cherry switches
2023-03-06 - New redesigned lever body with Cherry switches
    [mmhotas.kicad_sch]
2023-06-28 - New base plate
2023-08-01 - New lever joint
